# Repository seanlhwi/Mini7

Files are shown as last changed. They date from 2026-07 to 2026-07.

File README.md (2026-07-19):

# Mini7
A macro pad style custom drum pad with seven keys. This idea first reached me after yearning to try a drum set, but also wanted it to be portable. After pondering on what device type to use, I came across electronical drum pads, where each drum is practically a switch. It was at this moment when I thoguht about making the electronical drum set out of MX switches! Each of my keys are a different drum type, consisting of a base drum, high tom, mid tom, low tom, snare drum, hi-hat, and ride cymbal. Other key details are the battery monitoring screen and satisfying push button on/off button. The software was written on Aurduino IDE, and it is in a binary format to be flashed on a RP2040 Zero. Instead of just creating a box shape, the bottom two corners are cut to create a more interesting design. This project is easily recreatable by simply assemblying all of the parts according to the schematic and flashing the firmware. I hope to extend this drum system by making other types of drums too. Screenshot 2026-07-18 at 11 07 57 PM
Screenshot 2026-07-18 at 11 07 19 PM
Screenshot 2026-07-08 at 5 41 50 PM
# Mini7 Bill of Materials

| Name | Purpose | Quantity | Total (USD) | Link | Distributor |
|---|---|---|---|---|---|
| PCB | PCB | 5 | $10.40 | [View](https://cart.jlcpcb.com/shopcart/cart) | JLCPCB |
| Super Glue | Gluing | 1 | $2.72 | [View](https://www.aliexpress.us/item/3256808473825074.html) | Ali Express |
| MAX17048 Module | Battery monitor | 1 | $5.95 | [View](https://www.adafruit.com/product/5580) | Adafruit |
| Push Button | On/Off | 1 | $6.99 | [View](https://www.amazon.com/Cylewet-Self-Locking-Latching-Button-CYT1091/dp/B075VBV4QH) | Amazon |
| N52 Magnets | Securing Case | 10 | $2.56 | [View](https://www.aliexpress.us/item/3256810556183287.html) | Ali Express |
| 400mAh LiPo Battery | Battery | 1 | $8.99 | [View](https://www.amazon.com/Battery-Rechargeable-Lithium-Polymer-Connector/dp/B09F9W7Z6J) | Amazon |
| 0.91" OLED Screen | Battery Display | 2 | $5.99 | [View](https://www.amazon.com/Dorhea-Display-SSD1306-Arduino-3-3V-5V/dp/B07FMDB6TR) | Amazon |
| PCM5102A Module | Audio Output | 1 | $3.64 | [View](https://www.aliexpress.us/item/3256806642863761.html) | Ali Express |
| Tenstar RP2040 Zero | MCU | 2 | $5.19 | [View](https://www.aliexpress.us/item/3256806637247373.html) | Ali Express |
| TP4056 Module | Charging Unit | 1 | $1.39 | [View](https://www.aliexpress.us/item/3256808777213556.html) | Ali Express |
| 10 µF Capacitor | Capacitor | 50 | $3.10 | [View](https://www.aliexpress.us/item/3256807278239101.html) | Ali Express |
| 100nF Capacitor | Capacitor | 50 | $0.00 (Bundle) | [View](https://www.aliexpress.com/ssr/300001493/welcomegiftspmpc?productIds=1005007470747384) | Ali Express |
| 4.7k Resistors | Resistor | 1 | $2.88 | [View](https://www.aliexpress.com/ssr/300001493/welcomegiftspmpc?productIds=1005007470747384) | Ali Express |

## Totals

| Metric | Value |
|---|---|
| Total Number of Items | 13 |
| Total Number of Parts | 126 |
| **Total Cost** | **$59.80** |

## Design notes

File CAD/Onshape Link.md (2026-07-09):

https://cad.onshape.com/documents/0129fb89862530cc42c2ce25/w/a097cb49de0af5ff635fb2dd/e/6ec6c10f10f0d9740c31cf37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

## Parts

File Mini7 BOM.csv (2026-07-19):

Name | Purpose | Quantity | Total(USD) | Link | Distributor
PCB | PCB | 5 | 10.4 | https://cart.jlcpcb.com/shopcart/cart | JLCPCB
Super Glue | Gluing | 1 | 2.72 | https://www.aliexpress.us/item/3256808473825074.html?curPageLogUid=tDPOc6qNbFf7 | Ali Express
MAX17048 Module | Battery monitor | 1 | 5.95 | https://www.adafruit.com/product/5580 | Adafruit
Push Button | On/Off | 1 | 6.99 | https://www.amazon.com/Cylewet-Self-Locking-Latching-Button-CYT1091/dp/B075VBV4QH?s=industrial | Amazon
N52 Magnets | Securing Case | 10 | 2.56 | https://www.aliexpress.us/item/3256810556183287.html?curPageLogUid=iERVDQ7iZTk7 | Ali Express
400mAh LiPo Battery | Battery | 1 | 8.99 | https://www.amazon.com/Battery-Rechargeable-Lithium-Polymer-Connector/dp/B09F9W7Z6J | Amazon
0.91" Oled Screen | Battery Display | 2 | 5.99 | https://www.amazon.com/Dorhea-Display-SSD1306-Arduino-3-3V-5V/dp/B07FMDB6TR?s=electronics | Amazon
PCM5102A Module | Audio Output | 1 | 3.64 | https://www.aliexpress.us/item/3256806642863761.html?curPageLogUid=MBgyioBv2L80 | Ali Express
Tenstar rp2040 Zero | MCU | 2 | 5.19 | https://www.aliexpress.us/item/3256806637247373.html?curPageLogUid=tDq6DhZP6tD4 | Ali Express
TP4056 Module | Charging Unit | 1 | 1.39 | https://www.aliexpress.us/item/3256808777213556.html?curPageLogUid=r7lZNa7mUs0d | Ali Express
10 uF Capacitor | Capacitor | 50 | 3.1 | https://www.aliexpress.us/item/3256807278239101.html?curPageLogUid=rMfE4aosHMVz | Ali Express
100nF Capacitor | Capcitor | 50 | 0.00 (Bundle) | https://www.aliexpress.com/ssr/300001493/welcomegiftspmpc?businessCode=ug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 | Ali Express
4.7k Resistors | Resistor | 1 | 2.88 | https://www.aliexpress.com/ssr/300001493/welcomegiftspmpc?businessCode=ug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 | Ali Express

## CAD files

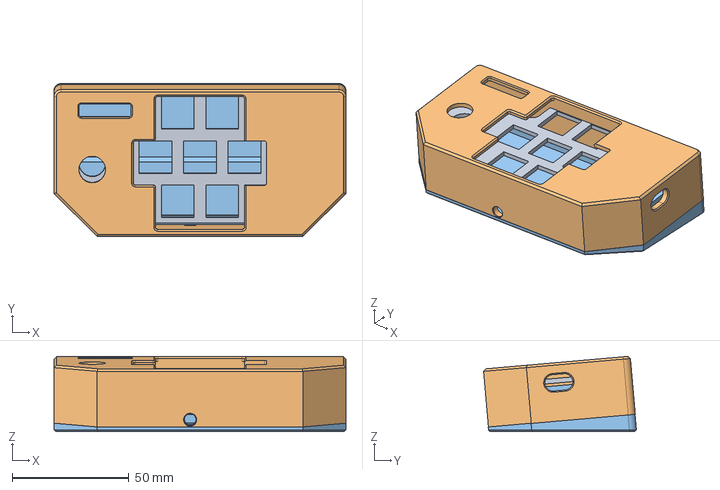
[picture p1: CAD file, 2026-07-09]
CAD/Parts Assembly.step
125.1 x 65.5 x 32.2 mm

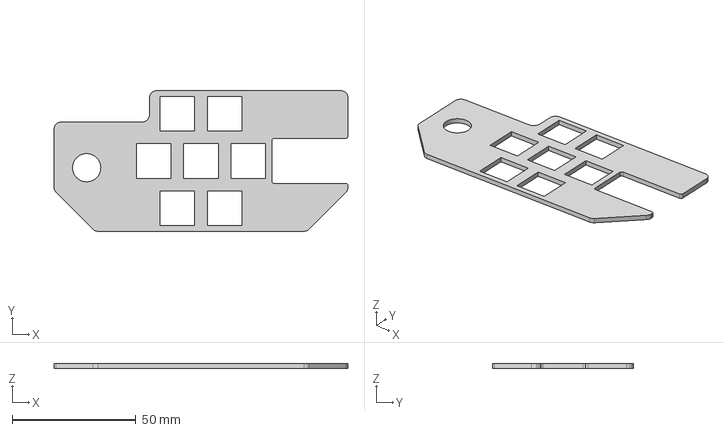
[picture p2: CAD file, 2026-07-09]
CAD/Plate (2).step
118.7 x 56.8 x 2.00 mm

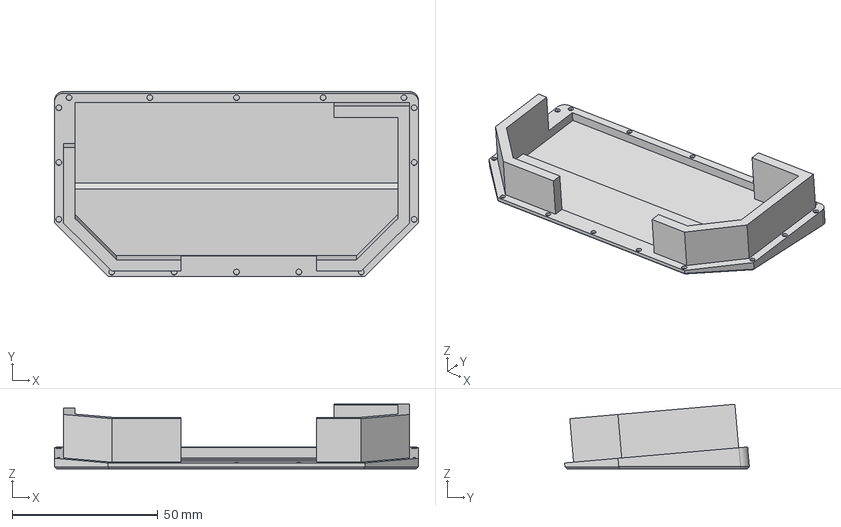
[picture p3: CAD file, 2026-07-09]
CAD/Bottom (2).step
125.1 x 63.5 x 22.2 mm

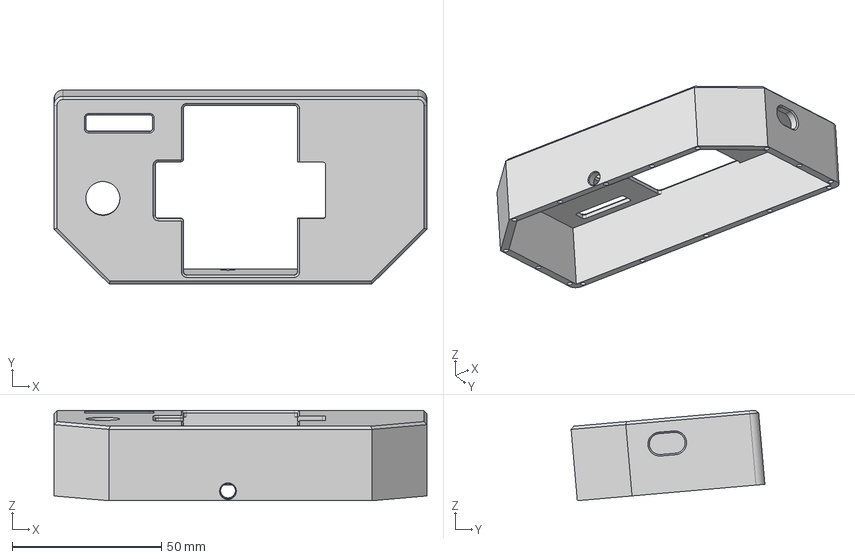
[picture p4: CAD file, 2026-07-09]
CAD/Top (2).step
125.1 x 65.0 x 30.3 mm

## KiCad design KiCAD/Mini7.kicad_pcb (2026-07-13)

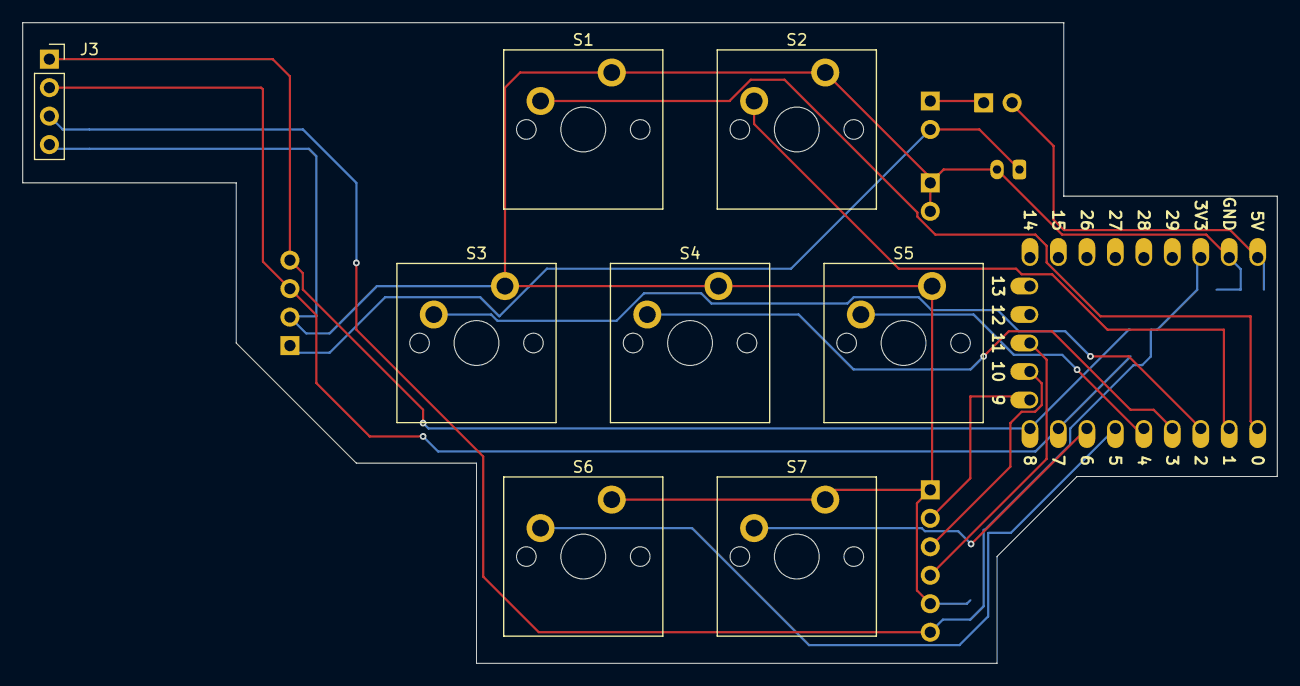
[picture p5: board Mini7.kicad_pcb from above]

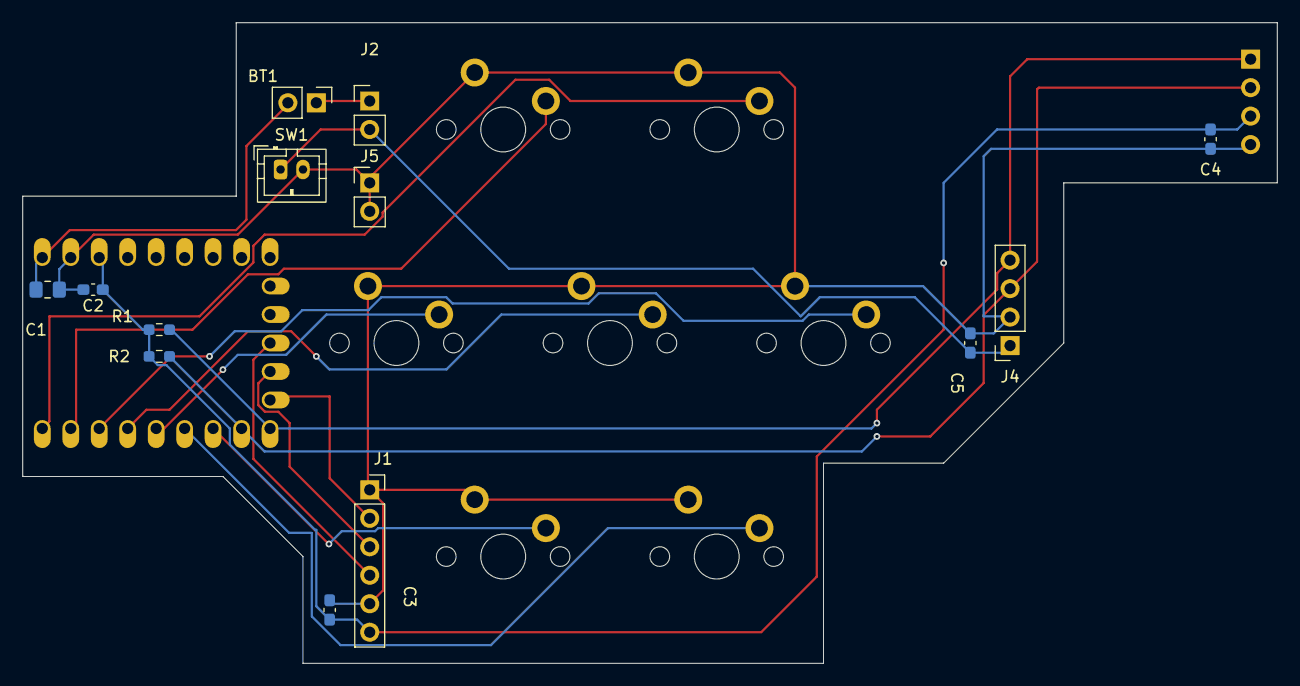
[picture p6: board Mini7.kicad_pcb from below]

Board: 2 copper layers, 111.9 x 57.1 mm, 22 parts (13 on the bottom side), 17 nets.

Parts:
BT1: LiPo; JST_PH_B2B-PH-K_1x02_P2.00mm_Vertical
C1: 10uF; C_0805_2012Metric_Pad1.18x1.45mm_HandSolder
C2, C3, C4, C5: 100nF; C_0603_1608Metric_Pad1.08x0.95mm_HandSolder
J1: PCM5102A; PinSocket_1x06_P2.54mm_Vertical
J2: TP4056 A; PinHeader_1x02_P2.54mm_Vertical
J3: OLED; PinSocket_1x04_P2.54mm_Vertical
J4: MAX17048; PinSocket_1x04_P2.54mm_Vertical
J5: TP4056 B; PinHeader_1x02_P2.54mm_Vertical
R1, R2: 4.7k; R_0603_1608Metric_Pad0.98x0.95mm_HandSolder
S1, S2, S3, S4, S5, S6, S7: MX_PCB_1.00u
SW1: Button; PinHeader_1x02_P2.54mm_Vertical
U1: RP2040_Zero

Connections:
+3V3: C2.1, C3.1, C4.1, J1.6 (VIN), J3.3 (VCC), R1.1, R2.1, U1.21 (3V3)
+BV: BT1.1 (Positive), C5.1, J2.2 (B+), J4.1 (VIN)
+SV: J2.1 (OUT+), SW1.1 (+SV)
+SWV: C1.1, SW1.2 (+SWV), U1.23 (5V)
GND: BT1.2 (Negative), C1.2, C2.2, C3.2, C4.2, C5.2, J1.1 (SCK), J1.5 (GND), J3.4 (GND), J4.2 (GND), J5.1 (B-), J5.2 (OUT-), S1.2, S2.2, S3.2, S4.2, S5.2, S6.2, S7.2, U1.22 (GND)
Pin10: J1.2 (BCK), U1.10 (9)
Pin11: J1.3 (DIN), U1.11 (10)
Pin12: J1.4 (LCK), U1.12 (11)
S1: S1.1, U1.1 (0)
S2: S2.1, U1.2 (1)
S3: S3.1, U1.3 (2)
S4: S4.1, U1.4 (3)
S5: S5.1, U1.5 (4)
S6: S6.1, U1.6 (5)
S7: S7.1, U1.7 (6)
SCL: J3.2 (SCL), J4.3 (SCL), R2.2, U1.8 (7)
SDA: J3.1 (SDA), J4.4 (SDA), R1.2, U1.9 (8)

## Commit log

2026-07-19 Rename Mini7 - 시트1.csv to Mini7 BOM.csv
    [Mini7 BOM.csv]
2026-07-19 Enhance README with project details and BOM
    Added detailed project description and Bill of Materials section to README.
